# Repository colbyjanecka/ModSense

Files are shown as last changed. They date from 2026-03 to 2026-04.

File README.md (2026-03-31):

# ModSense: Motion-Based CV for Eurorack

**Have you ever wanted to control your Eurorack patch with just your presence, or maybe add an invisible whammy bar to your ModCaster?**  Well, this 6 HP module allows you to use your bodily movement within your patch, enabling quick and effective live-performance control options.

## Schematic
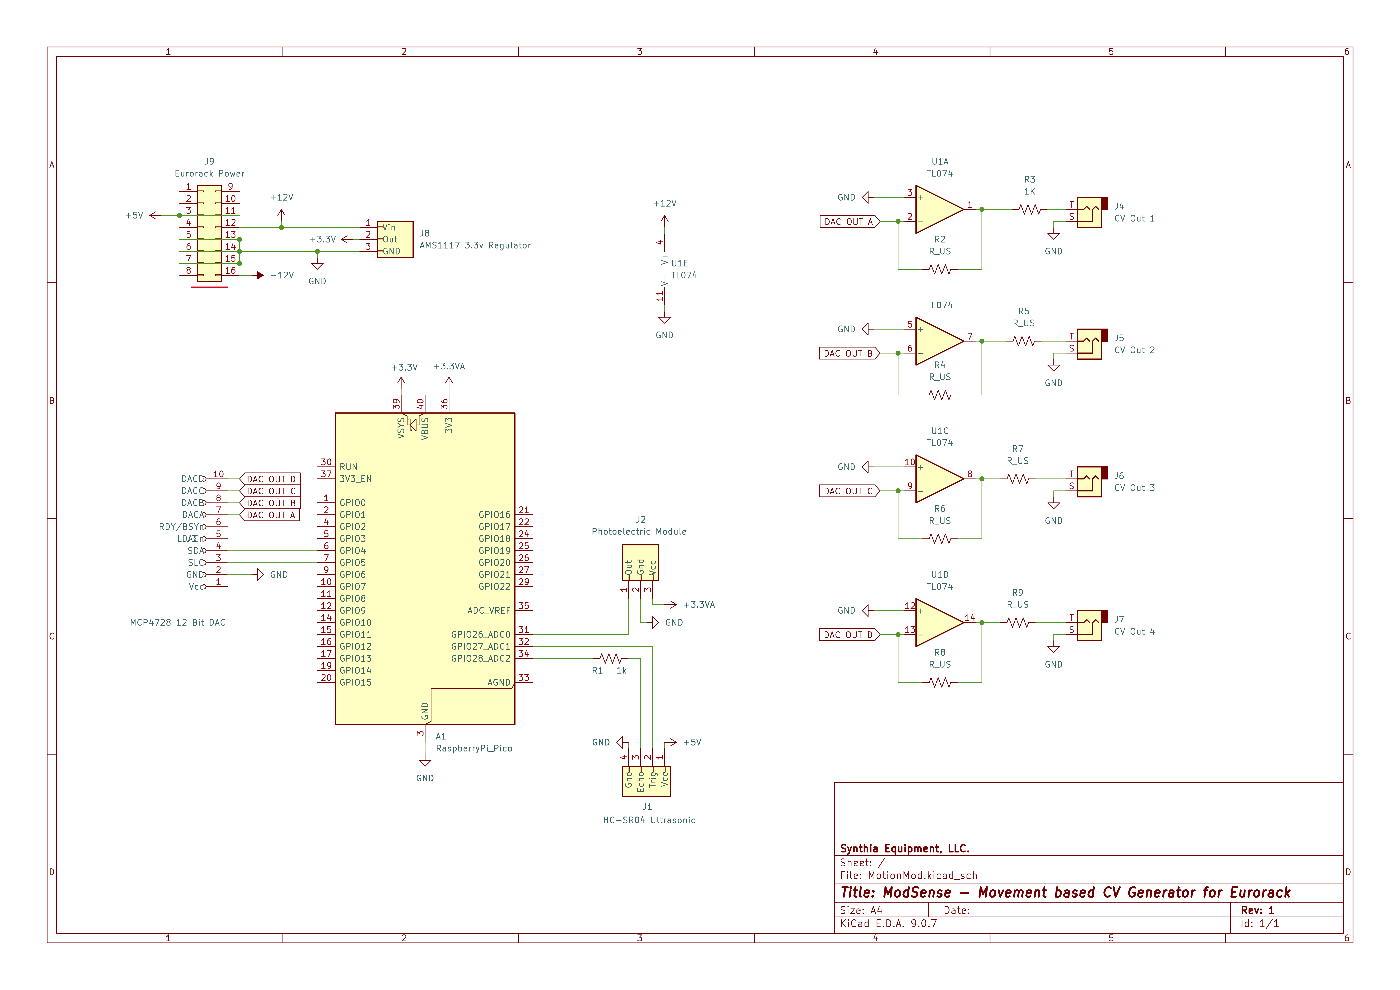
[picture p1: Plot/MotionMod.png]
schematic


## Features

- 4 x Programmable CV Out (0-12v)
- Generates Trigger Output when object presence is detected/changed
- Ultrasonic ranging transducer provides multi-functional outputs:
  - Detection area: 2cm~500cm;  precision: down to 0.3 cm
  - Example: distance and speed of detected object

## Parts

- Raspberry Pi Pico (RP2040)
- MCP4728 12 Bit I2C DAC
- TL074 Op-Amp
- HC-SR04 Ultrasonic Module
- Infrared Photoelectric Module (3-pin)

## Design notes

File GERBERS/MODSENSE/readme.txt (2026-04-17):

V-Cuts are in the V-CUT layer (User.Eco1).

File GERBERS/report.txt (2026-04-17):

Warning: Width correction constrained.  The width correction value must be in the range of [0.000001 mm; 0.199999 mm] for the current design rules.
Plotted to '/Users/hiplandic/Developer/KiCad/MotionMod/MotionMod-F_Cu.gbr'.
Plotted to '/Users/hiplandic/Developer/KiCad/MotionMod/MotionMod-B_Cu.gbr'.
Plotted to '/Users/hiplandic/Developer/KiCad/MotionMod/MotionMod-F_Paste.gbr'.
Plotted to '/Users/hiplandic/Developer/KiCad/MotionMod/MotionMod-B_Paste.gbr'.
Plotted to '/Users/hiplandic/Developer/KiCad/MotionMod/MotionMod-F_Silkscreen.gbr'.
Plotted to '/Users/hiplandic/Developer/KiCad/MotionMod/MotionMod-B_Silkscreen.gbr'.
Plotted to '/Users/hiplandic/Developer/KiCad/MotionMod/MotionMod-F_Mask.gbr'.
Plotted to '/Users/hiplandic/Developer/KiCad/MotionMod/MotionMod-B_Mask.gbr'.
Plotted to '/Users/hiplandic/Developer/KiCad/MotionMod/MotionMod-Edge_Cuts.gbr'.
Created Gerber job file '/Users/hiplandic/Developer/KiCad/MotionMod/MotionMod-job.gbrjob'.
Info: Done.
Plotted to '/Users/hiplandic/Developer/KiCad/MotionMod/MotionMod-F_Cu.gbr'.
Plotted to '/Users/hiplandic/Developer/KiCad/MotionMod/MotionMod-B_Cu.gbr'.
Plotted to '/Users/hiplandic/Developer/KiCad/MotionMod/MotionMod-F_Paste.gbr'.
Plotted to '/Users/hiplandic/Developer/KiCad/MotionMod/MotionMod-B_Paste.gbr'.
Plotted to '/Users/hiplandic/Developer/KiCad/MotionMod/MotionMod-F_Silkscreen.gbr'.
Plotted to '/Users/hiplandic/Developer/KiCad/MotionMod/MotionMod-B_Silkscreen.gbr'.
Plotted to '/Users/hiplandic/Developer/KiCad/MotionMod/MotionMod-F_Mask.gbr'.
Plotted to '/Users/hiplandic/Developer/KiCad/MotionMod/MotionMod-B_Mask.gbr'.
Plotted to '/Users/hiplandic/Developer/KiCad/MotionMod/MotionMod-Edge_Cuts.gbr'.
Created Gerber job file '/Users/hiplandic/Developer/KiCad/MotionMod/MotionMod-job.gbrjob'.
Info: Done.
Info: Done.
Info: Done.

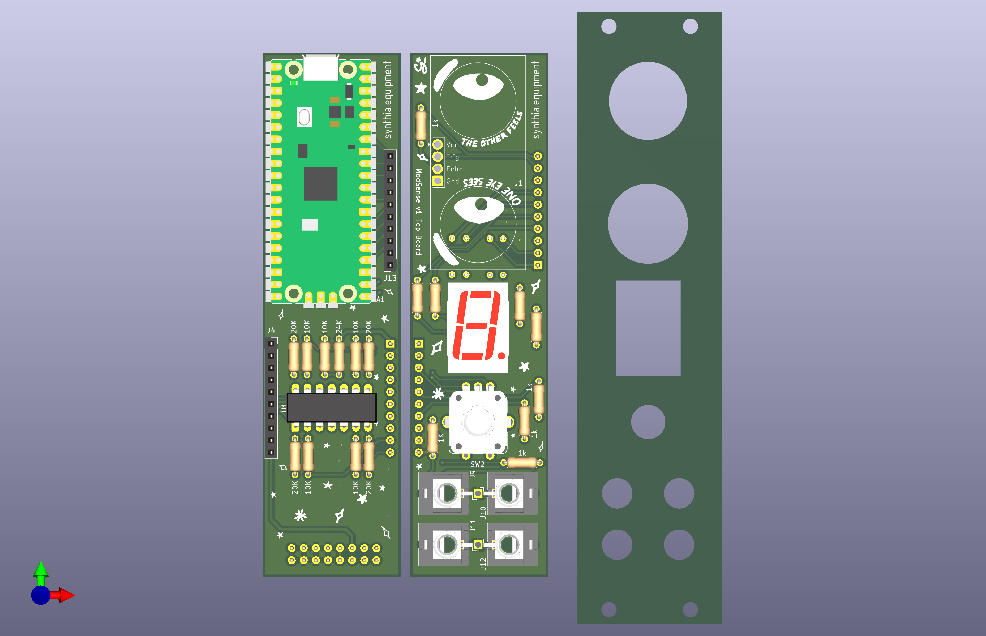
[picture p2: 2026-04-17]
MotionMod.png

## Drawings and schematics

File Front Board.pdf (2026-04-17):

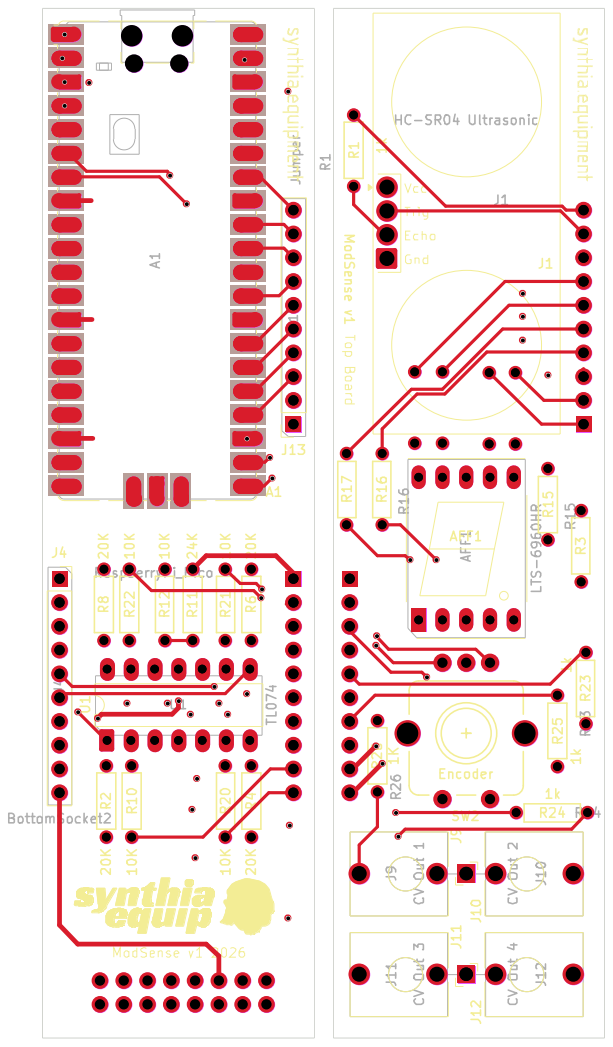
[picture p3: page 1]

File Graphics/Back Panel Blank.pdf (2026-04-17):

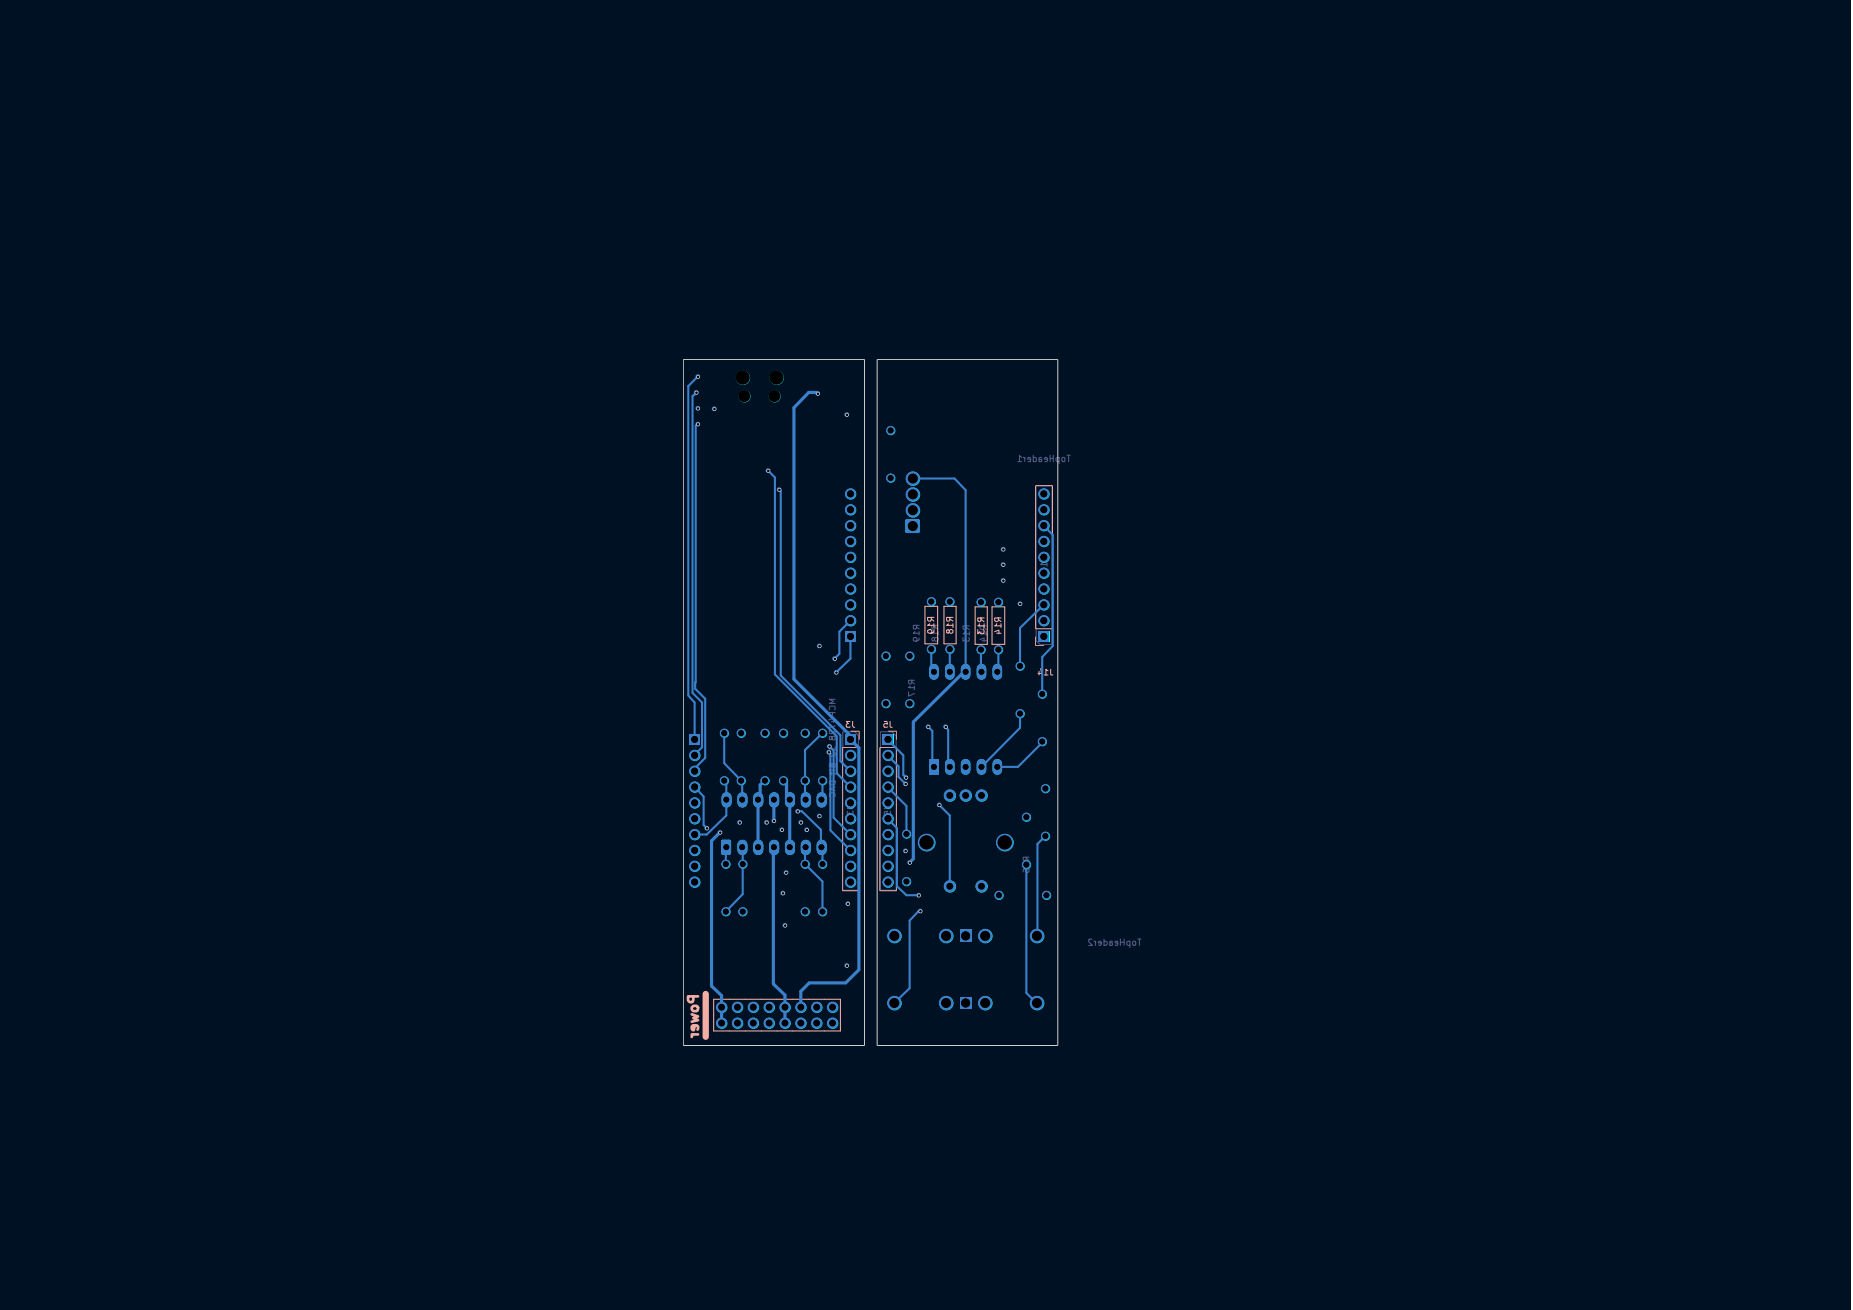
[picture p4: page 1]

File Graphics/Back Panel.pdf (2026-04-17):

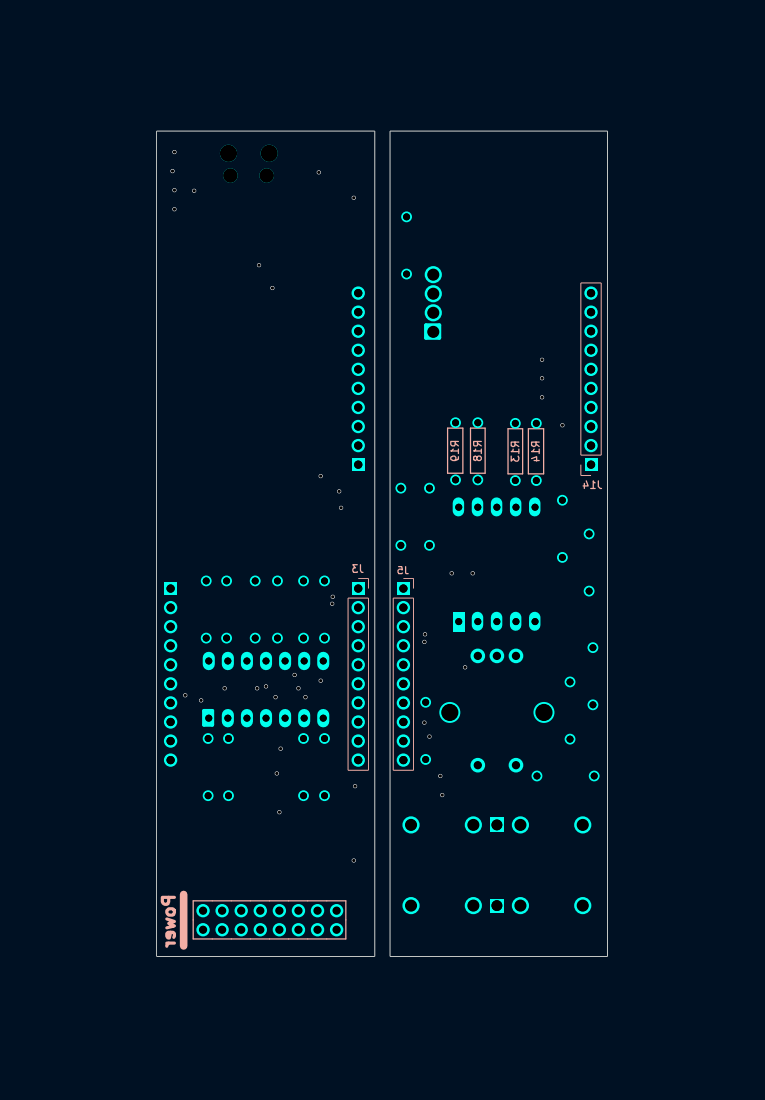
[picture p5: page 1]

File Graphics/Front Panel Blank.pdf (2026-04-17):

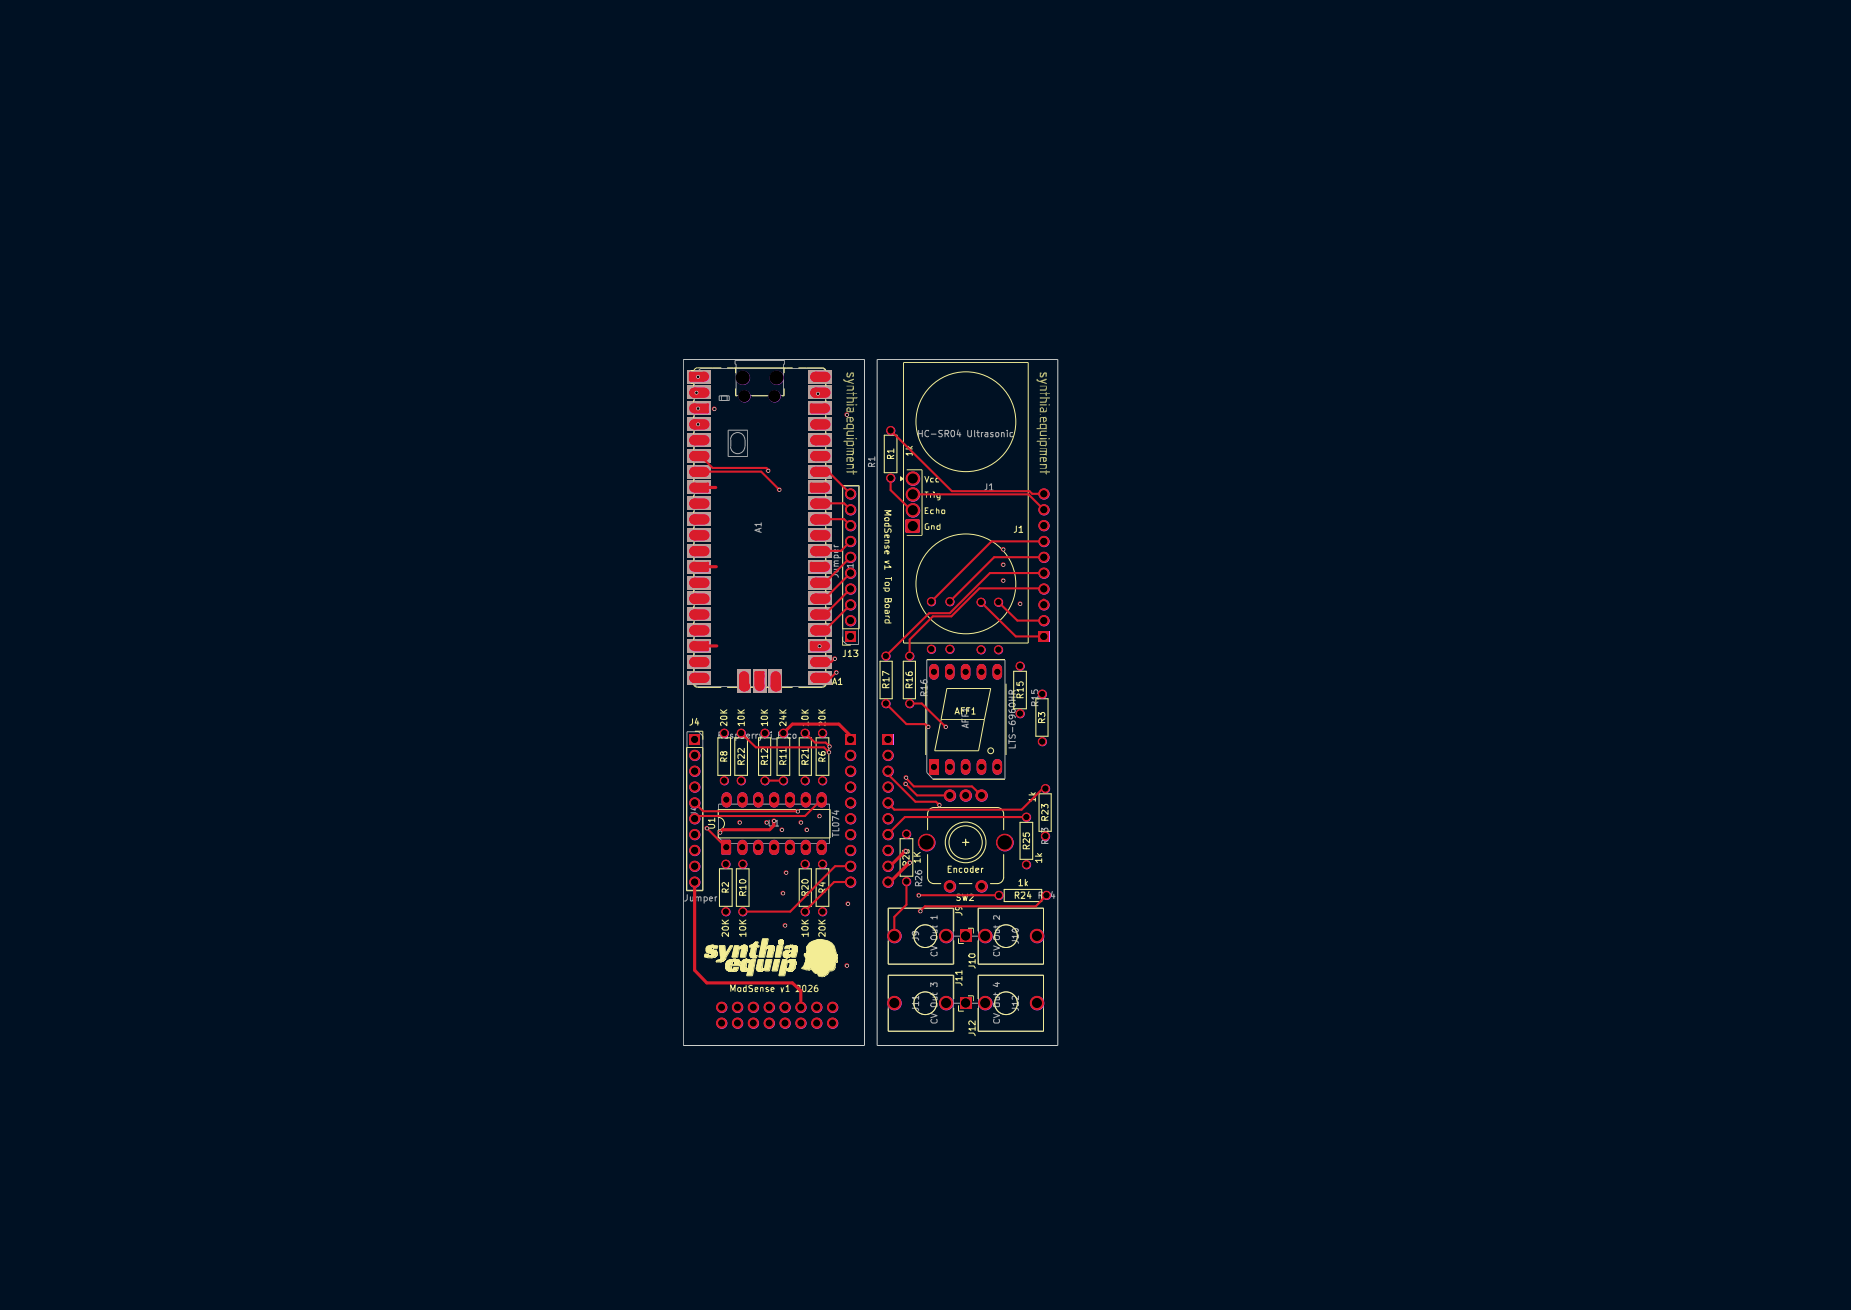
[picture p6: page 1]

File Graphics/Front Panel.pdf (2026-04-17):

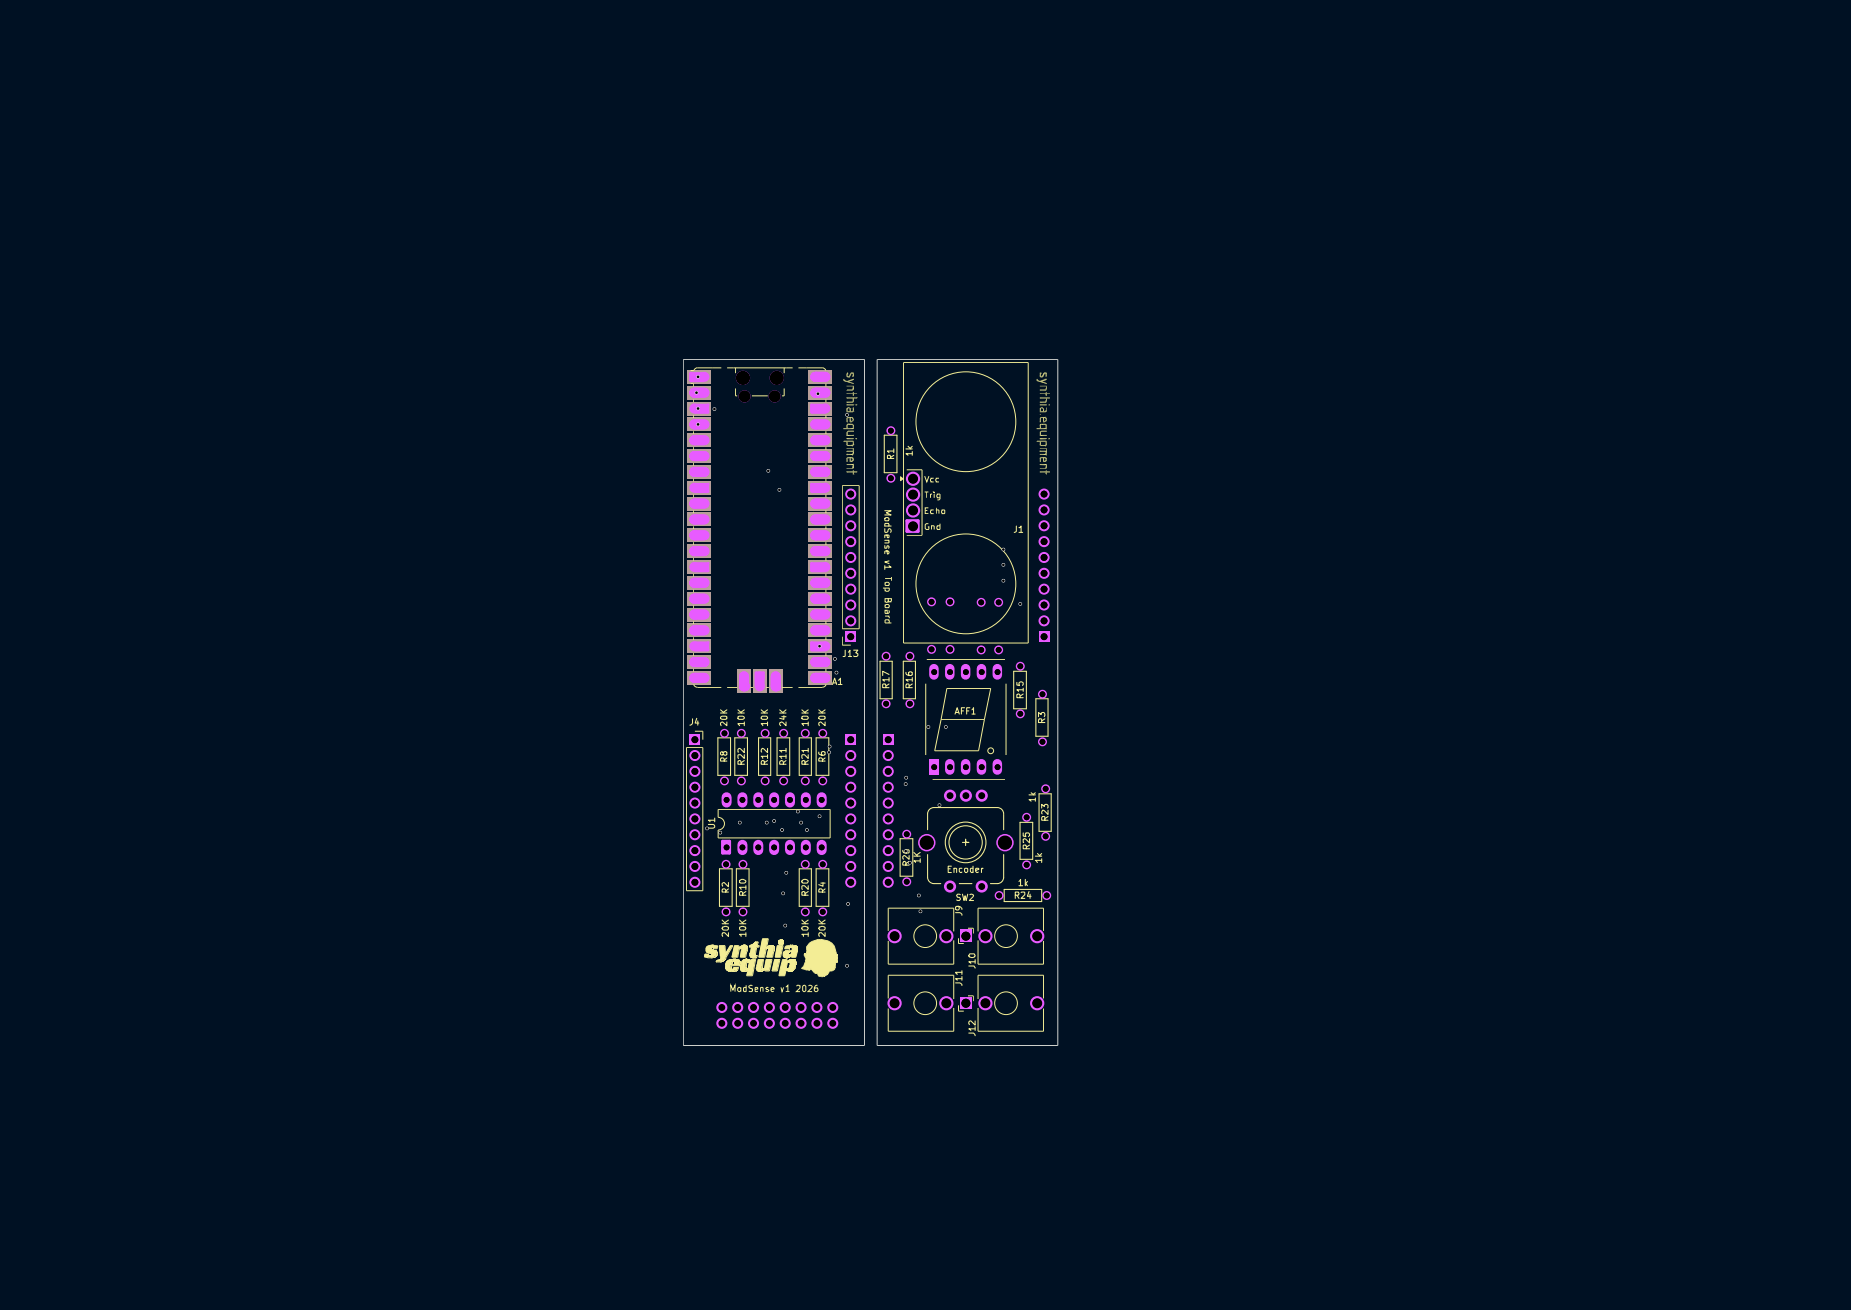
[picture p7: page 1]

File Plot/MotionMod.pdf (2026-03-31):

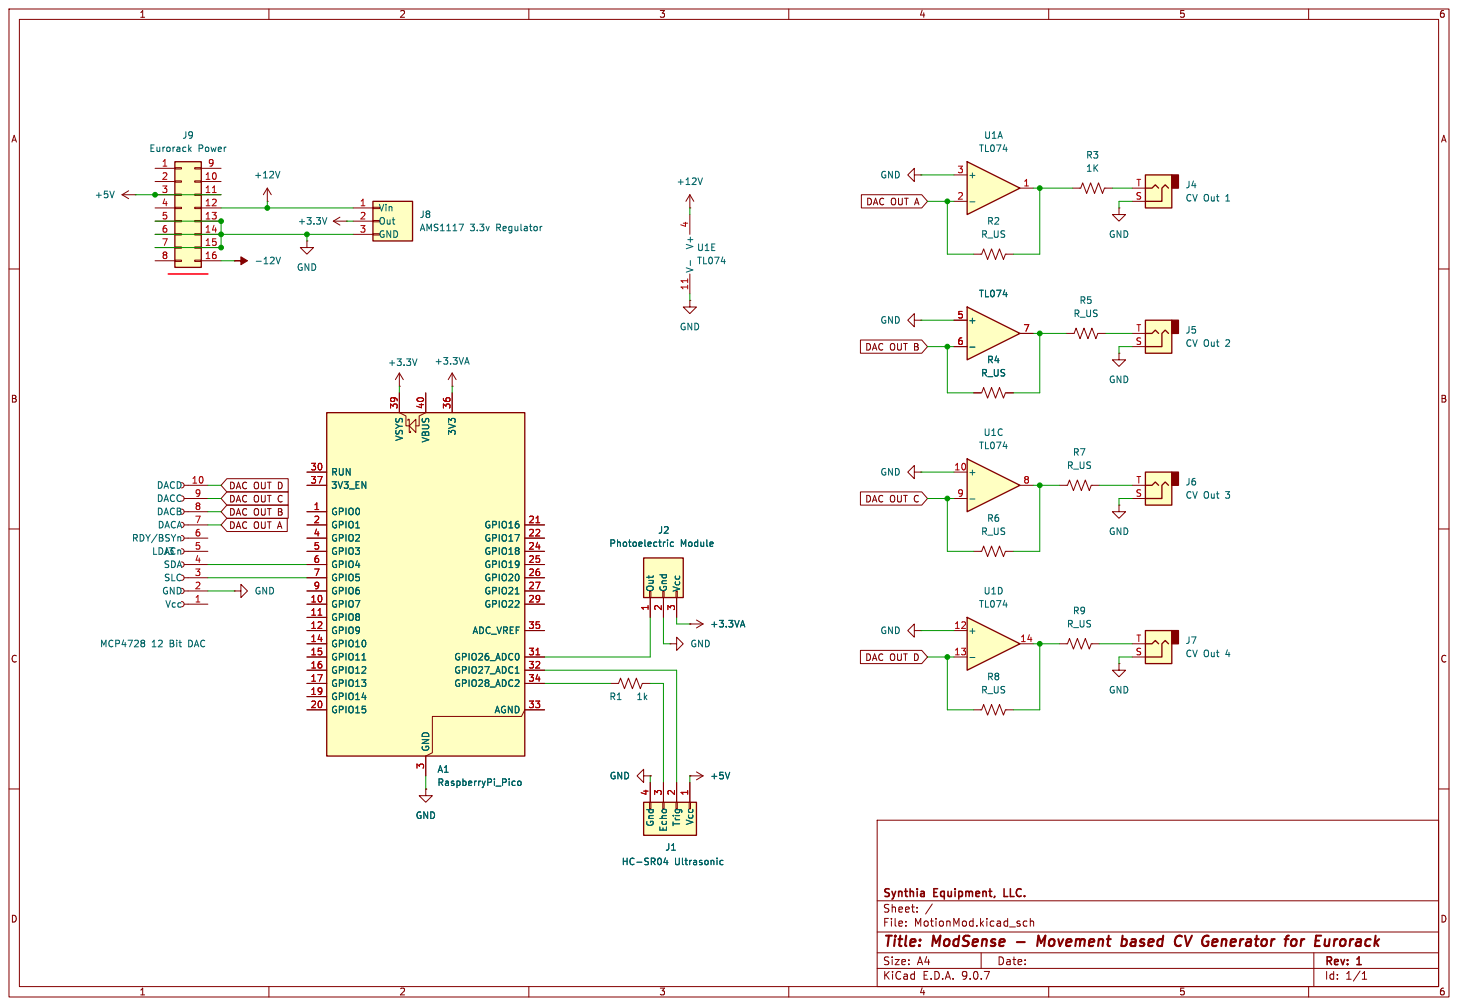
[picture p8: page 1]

DAC OUT A DAC OUT B DAC OUT C

Id: 1/1 Title: ModSense - Movement based CV Generator for Eurorack

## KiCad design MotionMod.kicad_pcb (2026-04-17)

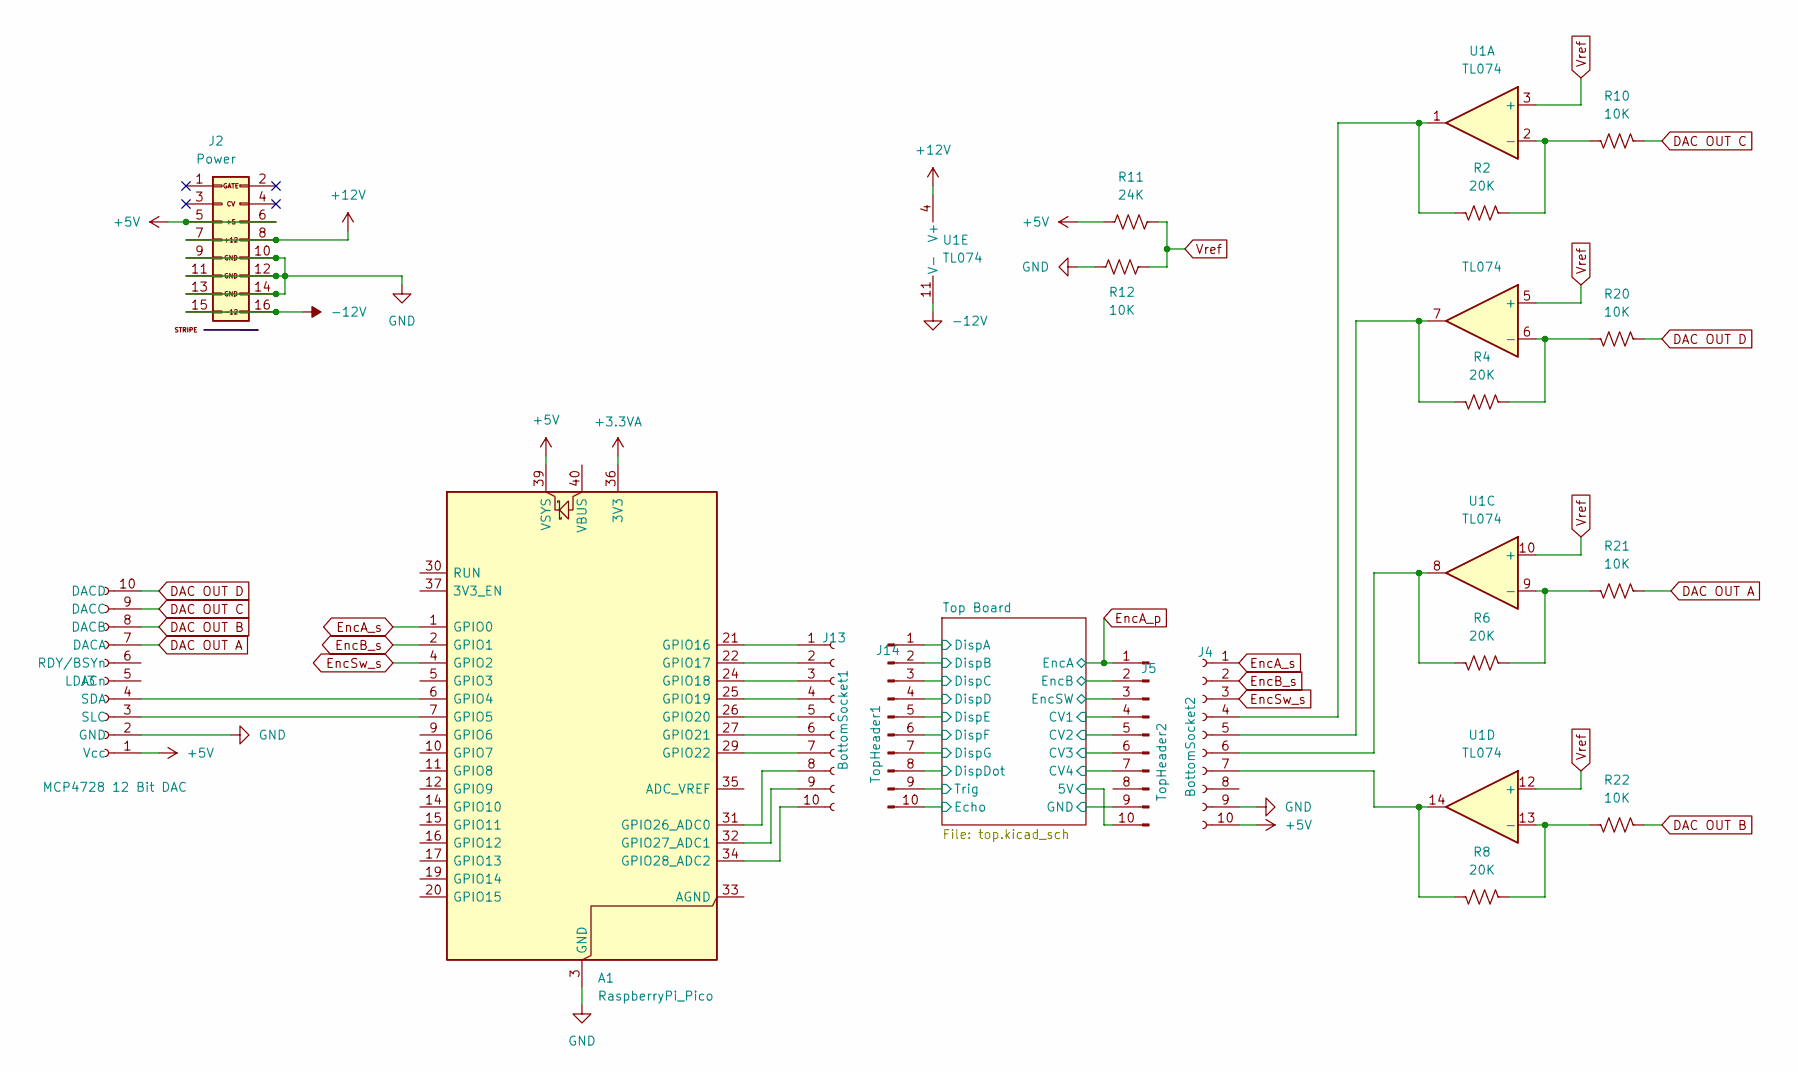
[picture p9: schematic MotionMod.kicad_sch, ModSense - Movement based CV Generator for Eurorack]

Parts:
A1: RaspberryPi_Pico; RaspberryPi_Pico_SMD_HandSolder
J2: Power; Pins_2x08_2.54mm_TH_EuroPower; Part Number 1-1602FBV0T
J3: MCP4728 12 Bit DAC; PinHeader_1x10_P2.54mm_Vertical
J4: BottomSocket2; PinSocket_1x10_P2.54mm_Vertical
J5: TopHeader2; PinHeader_1x10_P2.54mm_Vertical
J13: BottomSocket1; PinSocket_1x10_P2.54mm_Vertical
J14: TopHeader1; PinHeader_1x10_P2.54mm_Vertical
R2, R4, R6, R8: 20K; R_Axial_DIN0207_L6.3mm_D2.5mm_P7.62mm_Horizontal
R10, R12, R20, R21, R22: 10K; R_Axial_DIN0207_L6.3mm_D2.5mm_P7.62mm_Horizontal
R11: 24K; R_Axial_DIN0207_L6.3mm_D2.5mm_P7.62mm_Horizontal
U1: TL074; DIP-14_W7.62mm_LongPads

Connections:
+3.3VA: A1.36 (3V3)
+5V: A1.39 (VSYS), J2.5 (+12V), J2.6, J3.1 (Vcc), J4.10, J5.10, R11.1; also elsewhere on the board
+12V: J2.7 (12V), J2.8 (+12V), U1.4 (V+)
-12V: J2.15 (-12V), J2.16, U1.11 (V-)
/Top Board/CV1: J5.4; also elsewhere on the board
/Top Board/CV2: J5.5; also elsewhere on the board
/Top Board/CV3: J5.6; also elsewhere on the board
/Top Board/CV4: J5.7; also elsewhere on the board
/Top Board/DispA: J14.1; also elsewhere on the board
/Top Board/DispB: J14.2; also elsewhere on the board
/Top Board/DispC: J14.3; also elsewhere on the board
/Top Board/DispD: J14.4; also elsewhere on the board
/Top Board/DispDot: J14.8; also elsewhere on the board
/Top Board/DispE: J14.5; also elsewhere on the board
/Top Board/DispF: J14.6; also elsewhere on the board
/Top Board/DispG: J14.7; also elsewhere on the board
/Top Board/Echo: J14.10; also elsewhere on the board
/Top Board/EncB: J5.2; also elsewhere on the board
/Top Board/EncSW: J5.3; also elsewhere on the board
/Top Board/Trig: J14.9; also elsewhere on the board
DAC OUT A: J3.7 (DACA), R21.1
DAC OUT B: J3.8 (DACB), R22.1
DAC OUT C: J3.9 (DACC), R10.1
DAC OUT D: J3.10 (DACD), R20.1
EncA_p: J5.1; also elsewhere on the board
EncA_s: A1.1 (GPIO0), J4.1
EncB_s: A1.2 (GPIO1), J4.2
EncSw_s: A1.4 (GPIO2), J4.3
GND: A1.3 (GND), A1.8 (GND), A1.13 (GND), A1.18 (GND), A1.23 (GND), A1.28 (GND), A1.38 (GND), J2.9 (GND), J2.10 (GND), J2.11 (GND), J2.12 (GND), J2.13 (-12), J2.14 (-12V), J3.2 (GND), J4.9, J5.9, R12.1; also elsewhere on the board
unnamed: A1.6 (GPIO4), J3.4 (SDA)
unnamed: A1.7 (GPIO5), J3.3 (SLC)
unnamed: A1.21 (GPIO16), J13.1
unnamed: A1.22 (GPIO17), J13.2
unnamed: A1.24 (GPIO18), J13.3
unnamed: A1.25 (GPIO19), J13.4
unnamed: A1.26 (GPIO20), J13.5
unnamed: A1.27 (GPIO21), J13.6
unnamed: A1.29 (GPIO22), J13.7
unnamed: A1.31 (GPIO26_ADC0), J13.8
unnamed: A1.32 (GPIO27_ADC1), J13.9
unnamed: A1.34 (GPIO28_ADC2), J13.10
unnamed: J4.4, R2.2, U1.1
unnamed: J4.5, R4.2, U1.7
unnamed: J4.6, R6.2, U1.8
unnamed: J4.7, R8.2, U1.14
unnamed: R2.1, R10.2, U1.2 (-)
unnamed: R4.1, R20.2, U1.6 (-)
unnamed: R6.1, R21.2, U1.9 (-)
unnamed: R8.1, R22.2, U1.13 (-)
Vref: R11.2, R12.2, U1.3 (+), U1.5 (+), U1.10 (+), U1.12 (+)

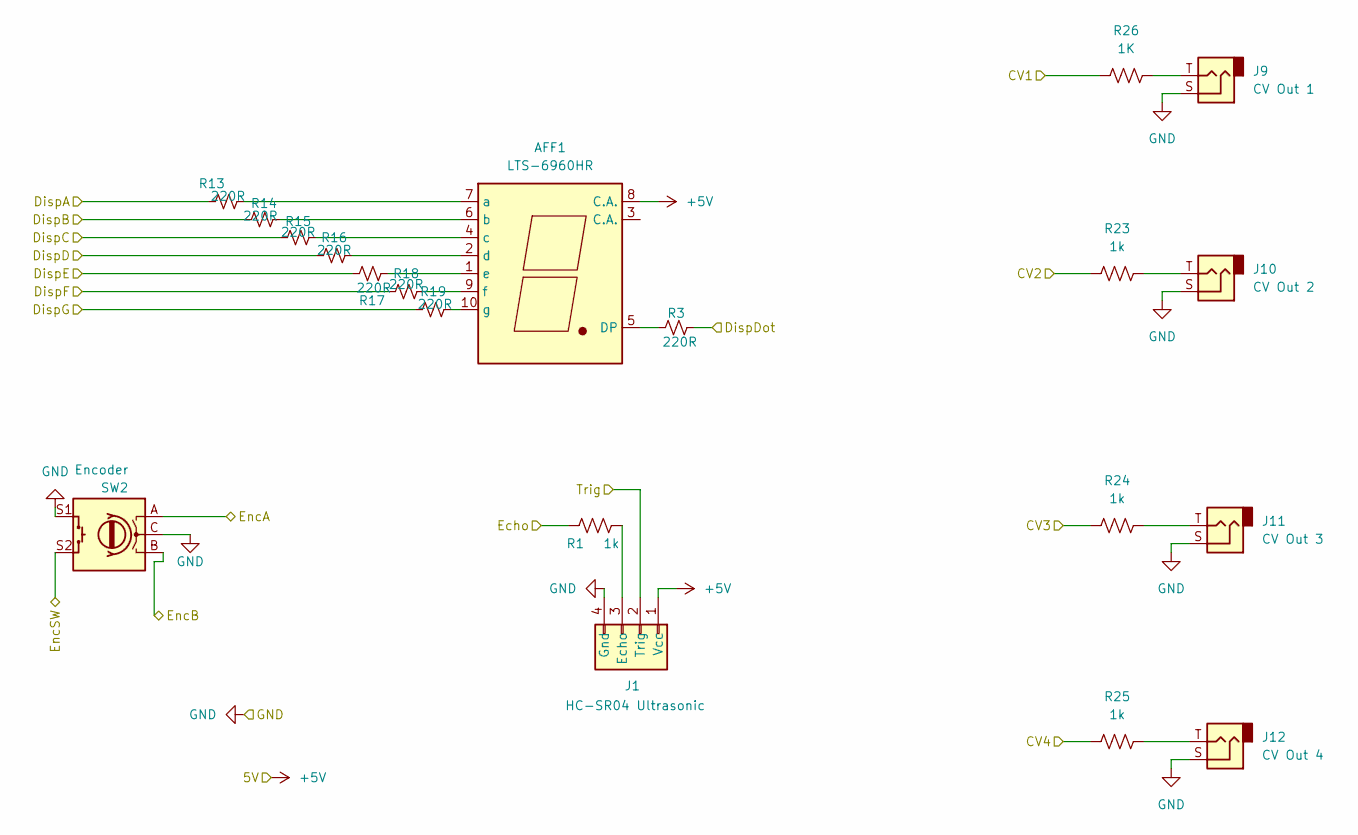
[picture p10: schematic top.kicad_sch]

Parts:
AFF1: LTS-6960HR; 7SegmentLED_LTS6760_LTS6780
J1: HC-SR04 Ultrasonic; Ultrasonic_Module_HC-SR04
J9: CV Out 1; Jack_3.5mm_QingPu_WQP-PJ398SM_Vertical_CircularHoles
J10: CV Out 2; Jack_3.5mm_QingPu_WQP-PJ398SM_Vertical_CircularHoles
J11: CV Out 3; Jack_3.5mm_QingPu_WQP-PJ398SM_Vertical_CircularHoles
J12: CV Out 4; Jack_3.5mm_QingPu_WQP-PJ398SM_Vertical_CircularHoles
R1, R23, R24, R25: 1k; R_Axial_DIN0207_L6.3mm_D2.5mm_P7.62mm_Horizontal
R3, R13, R14, R15, R16, R17, R18, R19: 220R; R_Axial_DIN0207_L6.3mm_D2.5mm_P7.62mm_Horizontal
R26: 1K; R_Axial_DIN0207_L6.3mm_D2.5mm_P7.62mm_Horizontal
SW2: Encoder; ENC_SPST_12mm

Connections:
+5V: AFF1.8 (C.A.), J1.1 (Vcc); also elsewhere on the board
/Top Board/CV1: R26.1; also elsewhere on the board
/Top Board/CV2: R23.1; also elsewhere on the board
/Top Board/CV3: R24.1; also elsewhere on the board
/Top Board/CV4: R25.1; also elsewhere on the board
/Top Board/DispA: R13.1; also elsewhere on the board
/Top Board/DispB: R14.1; also elsewhere on the board
/Top Board/DispC: R15.1; also elsewhere on the board
/Top Board/DispD: R16.1; also elsewhere on the board
/Top Board/DispDot: R3.2; also elsewhere on the board
/Top Board/DispE: R17.1; also elsewhere on the board
/Top Board/DispF: R18.1; also elsewhere on the board
/Top Board/DispG: R19.1; also elsewhere on the board
/Top Board/Echo: R1.1; also elsewhere on the board
/Top Board/EncB: SW2.B; also elsewhere on the board
/Top Board/EncSW: SW2.S2; also elsewhere on the board
/Top Board/Trig: J1.2 (Trig); also elsewhere on the board
EncA_p: SW2.A; also elsewhere on the board
GND: J1.4 (Gnd), J9.S, J10.S, J11.S, J12.S, SW2.C, SW2.S1; also elsewhere on the board
unnamed: AFF1.5 (DP), R3.1
unnamed: AFF1.7 (a), R13.2
unnamed: AFF1.6 (b), R14.2
unnamed: AFF1.4 (c), R15.2
unnamed: AFF1.2 (d), R16.2
unnamed: AFF1.1 (e), R17.2
unnamed: AFF1.9 (f), R18.2
unnamed: AFF1.10 (g), R19.2
unnamed: J1.3 (Echo), R1.2
unnamed: J9.T, R26.2
unnamed: J10.T, R23.2
unnamed: J11.T, R24.2
unnamed: J12.T, R25.2

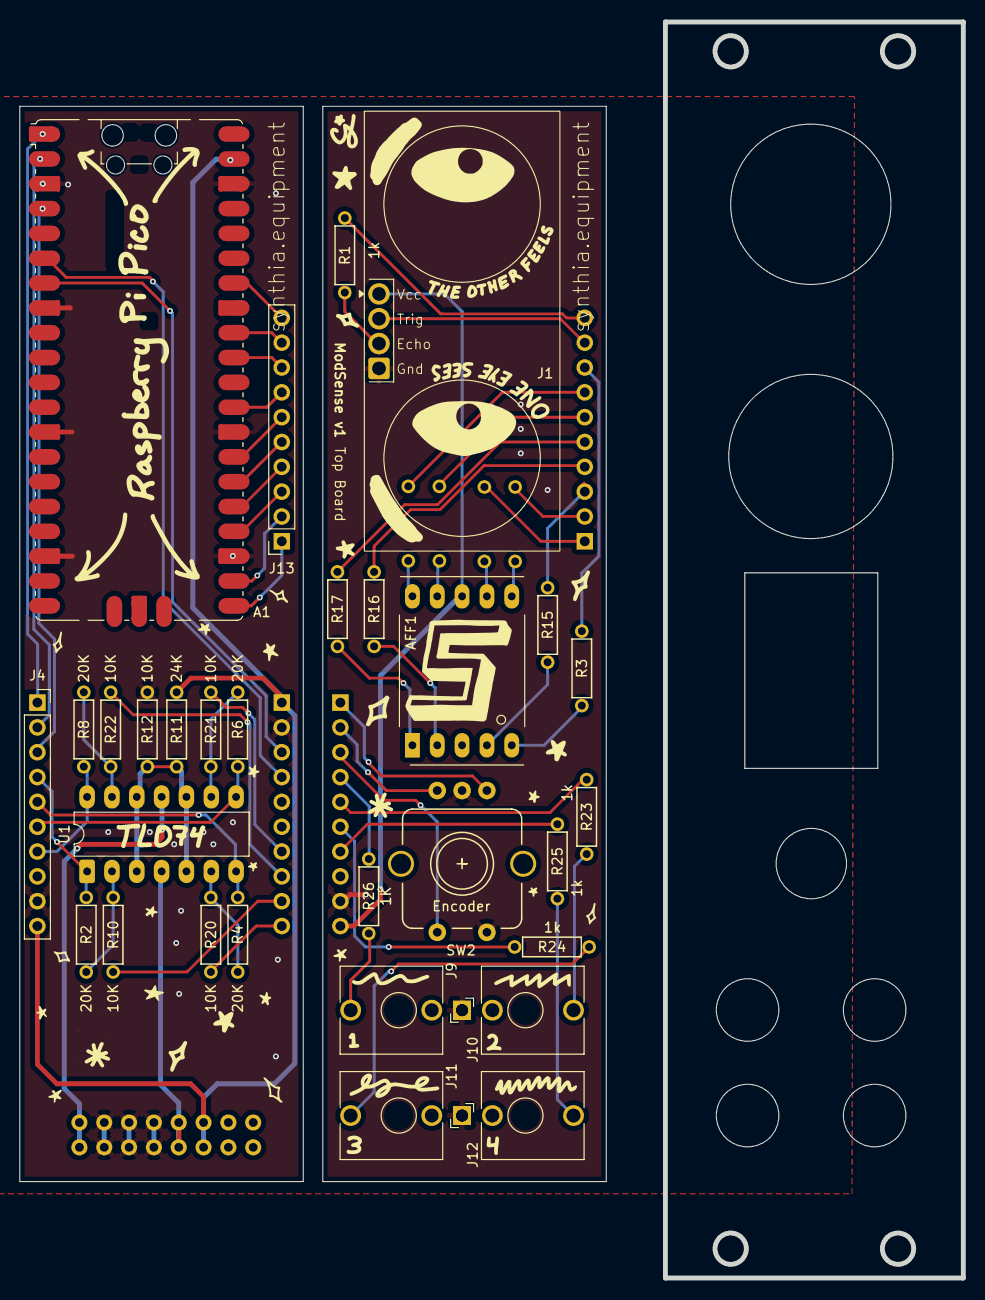
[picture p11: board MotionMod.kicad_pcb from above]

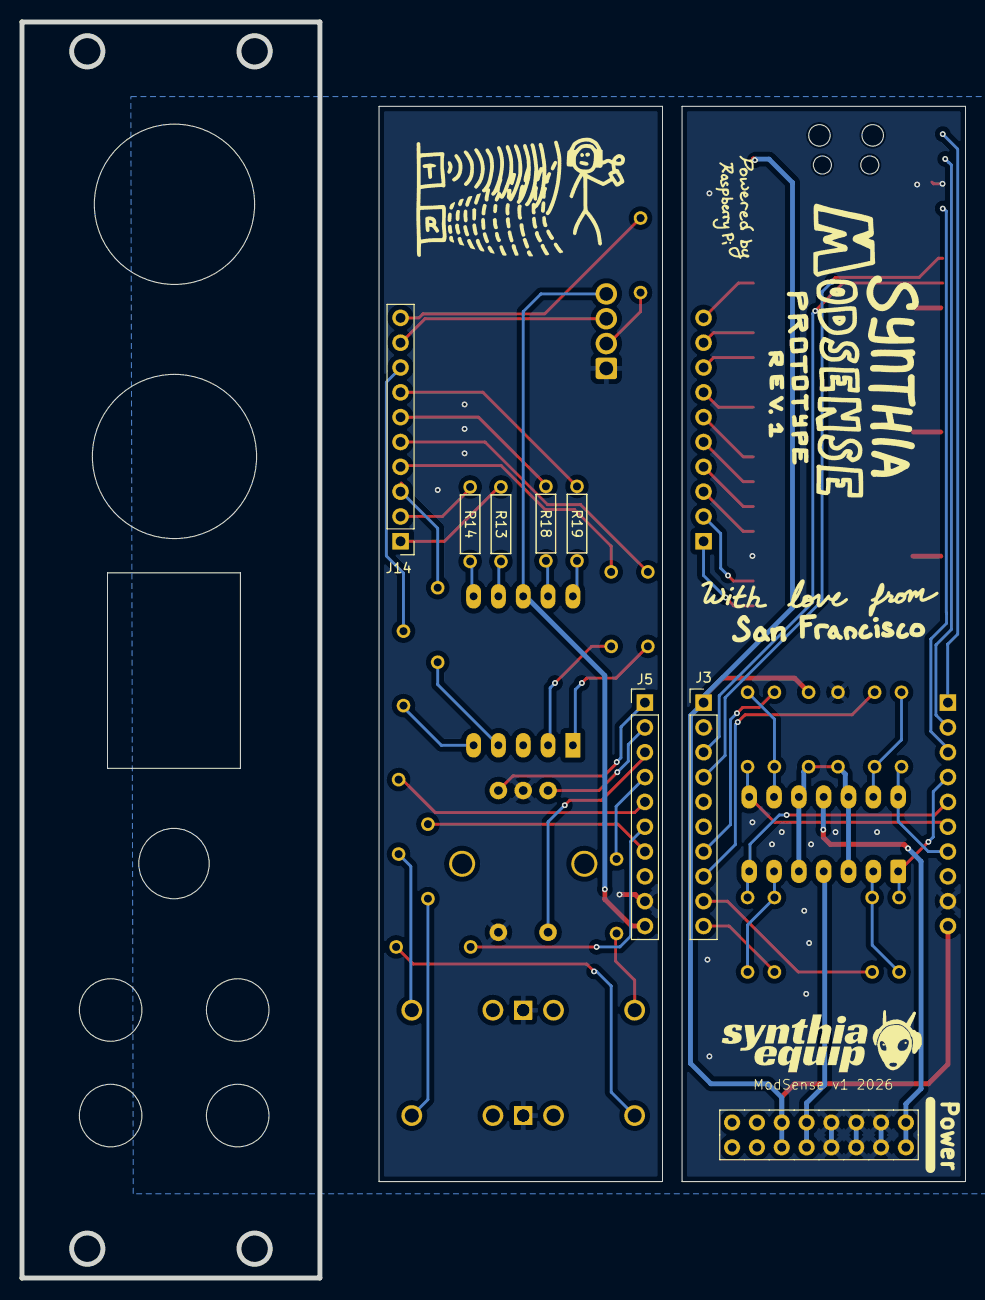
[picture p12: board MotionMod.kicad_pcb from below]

Board: 2 copper layers, 96.5 x 128.5 mm, 38 parts (8 on the bottom side), 62 nets.

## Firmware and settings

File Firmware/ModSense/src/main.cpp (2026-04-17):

#include <Arduino.h>
#include <Adafruit_MCP4728.h>
#include <Wire.h>

#ifndef LED_BUILTIN
#define LED_BUILTIN 25
#endif

Adafruit_MCP4728 mcp;

const int irPin = 26;
const int trigPin = 27;
const int echoPin = 28;

const uint8_t segPins[] = {17,16,14,13,12,18,19}; // a b c d e f g dp
const bool COMMON_ANODE = true;
const uint8_t digitMap[10] = {
  0b00111111, // 0
  0b00000110, // 1
  0b01011011, // 2
  0b01001111, // 3
  0b01100110, // 4
  0b01101101, // 5
  0b01111101, // 6
  0b00000111, // 7
  0b01111111, // 8
  0b01101111  // 9
};

void setSegment(uint8_t pin, bool on) {
  if (COMMON_ANODE) digitalWrite(pin, on ? LOW : HIGH);
  else digitalWrite(pin, on ? HIGH : LOW);
}

void showDigit(uint8_t d) {
  uint8_t mask = digitMap[d % 10];
  for (int i = 0; i < 8; i++) {
    setSegment(segPins[i], mask & (1 << i));
  }
}

//Encoder Setup
const int encA = 1;
const int encB = 0;
const int encSW = 2;


int encoderValue = 0;
int displayValue = 0;
int lastEncA = HIGH;


int readEncoderStep() {
  static int lastA = HIGH;
  static unsigned long lastStepTime = 0;
  const unsigned long debounceMs = 3;

  int a = digitalRead(encA);
  if (a == lastA) return 0;

  if (millis() - lastStepTime < debounceMs) {
    lastA = a;
    return 0;
  }

  lastStepTime = millis();
  lastA = a;

  if (digitalRead(encB) != a) return +1;
  return -1;
}

void updateEncoder() {
  static bool lastButton = HIGH;
  int step = readEncoderStep();
  if (step != 0) {
    encoderValue += step;

    if (encoderValue > 9) encoderValue = 9;
    if (encoderValue < 0) encoderValue = 0;

    displayValue = encoderValue;
  }
  bool button = digitalRead(encSW);
  if (lastButton == HIGH && button == LOW) {
    encoderValue = 0;
    displayValue = 0;
  }
  lastButton = button;
}

float distanceCm = 0;
int irValue = 0;

uint16_t clamp12(int v) {
  if (v < 0) return 0;
  if (v > 4095) return 4095;
  return (uint16_t)v;
}

void sendToDAC(MCP4728_channel_t channel, uint16_t value) {
  mcp.setChannelValue(channel, value);
}

float getDistanceCm() {
  digitalWrite(trigPin, LOW);
  delayMicroseconds(2);
  digitalWrite(trigPin, HIGH);
  delayMicroseconds(10);
  digitalWrite(trigPin, LOW);

  unsigned long duration = pulseIn(echoPin, HIGH, 30000);
  if (duration == 0) return -1.0f;

  return (duration * 0.0343f) / 2.0f;
}

int getIR() {
  return analogRead(irPin);
}
const float distanceMin = 4.0f;
const float distanceMax = 70.0f;   // change this to extend range

uint16_t cvA(float d) {
  if (d < 0) return 0;
  d = constrain(d, distanceMin, distanceMax);
  float norm = (d - distanceMin) / (distanceMax - distanceMin); // 0..1
  float bipolar = (norm * 2.0f) - 1.0f;                           // -1..+1
  int dac = (int)(2048.0f + bipolar * 2047.0f);                  // centered
  //Serial.println("DAC: " + String(dac));
  return clamp12(dac);
}

uint16_t cvB(int ir) {
  return clamp12(ir);
}

uint16_t cvC(float d, int ir) {
  float a = (d < 0) ? 0.0f : constrain((d - 5.0f) / 95.0f, 0.0f, 1.0f);
  float b = constrain(ir / 4095.0f, 0.0f, 1.0f);
  return clamp12((int)((a * 0.7f + b * 0.3f) * 4095.0f));
}

uint16_t cvD() {
  return clamp12((millis() / 10) % 4096);
}

float cvAFiltered = 0;
float cvBFiltered = 0;
float cvCFiltered = 0;
float cvDFiltered = 0;



void statusOK() {
  digitalWrite(LED_BUILTIN, HIGH);
}

void statusError() {
  while (true) {
    digitalWrite(LED_BUILTIN, HIGH);
    delay(100);
    digitalWrite(LED_BUILTIN, LOW);
    delay(100);
  }
}

uint16_t sine(uint16_t input) {
  if (input < 20){
    input = 4095;
  }
  return (input-10);

}

float distanceFiltered = -1.0f;

float smoothValue(float current, float target, float alpha) {
  return current + alpha * (target - current);
}



void setup() {
  pinMode(trigPin, OUTPUT);
  pinMode(echoPin, INPUT);
  pinMode(irPin, INPUT);
  pinMode(LED_BUILTIN, OUTPUT);

  //Seven Segment Display
  for (auto pin : segPins) {
    pinMode(pin, OUTPUT);
    digitalWrite(pin, HIGH);
  }

  //Encoder Setup
  pinMode(encA, INPUT_PULLUP);
  pinMode(encB, INPUT_PULLUP);
  pinMode(encSW, INPUT_PULLUP);
  lastEncA = digitalRead(encA);

  Serial.begin(115200);
  delay(4500);
  Serial.println("booting");

  if (!mcp.begin()) {
    statusError();
  Serial.println("MCP not found");
  }
  sendToDAC(MCP4728_CHANNEL_A, clamp12(0));
  showDigit(0);
  Serial.println("0");
  delay(1000);
  sendToDAC(MCP4728_CHANNEL_A, clamp12(1024));
  showDigit(1);
  Serial.println("1");
  delay(1000);
  sendToDAC(MCP4728_CHANNEL_A, 2048);
  showDigit(2);
  Serial.println("2");
  delay(1000);
  sendToDAC(MCP4728_CHANNEL_A, 4095);
  showDigit(3);
  Serial.println("3");
  delay(500);

  Serial.println("Testing Channel C");
  sendToDAC(MCP4728_CHANNEL_C, clamp12(0));
  showDigit(0);
  Serial.println("0");
  delay(1000);
  sendToDAC(MCP4728_CHANNEL_C, clamp12(1024));
  showDigit(1);
  Serial.println("1");
  delay(1000);
  sendToDAC(MCP4728_CHANNEL_C, 2048);
  showDigit(2);
  Serial.println("2");
  delay(1000);
  sendToDAC(MCP4728_CHANNEL_C, 4095);
  showDigit(3);
  Serial.println("3");
  delay(500);

  statusOK();
}

uint16_t output = 1024;

void loop() {
  float d = getDistanceCm();
  if (d >= 0) {
    if (distanceFiltered < 0) distanceFiltered = d;
    else distanceFiltered = smoothValue(distanceFiltered, d, 0.1f);
  }

  uint16_t aOut = cvA(distanceFiltered);

  output = sine(output);
  //Serial.println("a: " + String(aOut));
  sendToDAC(MCP4728_CHANNEL_A, aOut);
  sendToDAC(MCP4728_CHANNEL_B, aOut);
  sendToDAC(MCP4728_CHANNEL_C, aOut);

  //Serial.println("Setting DAC A+B to minimum value");
  //sendToDAC(MCP4728_CHANNEL_B, 0);
  //sendToDAC(MCP4728_CHANNEL_A, 0);
  //delay(4000);
  //Serial.println("Setting DAC A+B to maximum value");
  //sendToDAC(MCP4728_CHANNEL_B, 4095);
  //sendToDAC(MCP4728_CHANNEL_A, 4095);
  //delay(4000);
  
  //sendToDAC(MCP4728_CHANNEL_B, cvB(irValue));
  //sendToDAC(MCP4728_CHANNEL_C, cvC(distanceCm, irValue));
  //sendToDAC(MCP4728_CHANNEL_D, cvD());

  //TESTING encoder
  updateEncoder();
  showDigit(displayValue);
  //Serial.println(displayValue);

  statusOK();

  //delay(1);
}

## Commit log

2026-03-31 rev 1
    [MotionMod.kicad_pcb, MotionMod.kicad_sch]
2026-03-31 added sch image and pdf
    [MotionMod.kicad_sch]
2026-04-17 final gerbers for v1
    [MotionMod-B_Cu.gbr, MotionMod-B_Mask.gbr, MotionMod-B_Paste.gbr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]
